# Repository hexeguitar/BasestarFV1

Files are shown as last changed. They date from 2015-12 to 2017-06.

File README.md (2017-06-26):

Basestar FV-1
========

### Spin Semiconductor FV-1 DSP development board

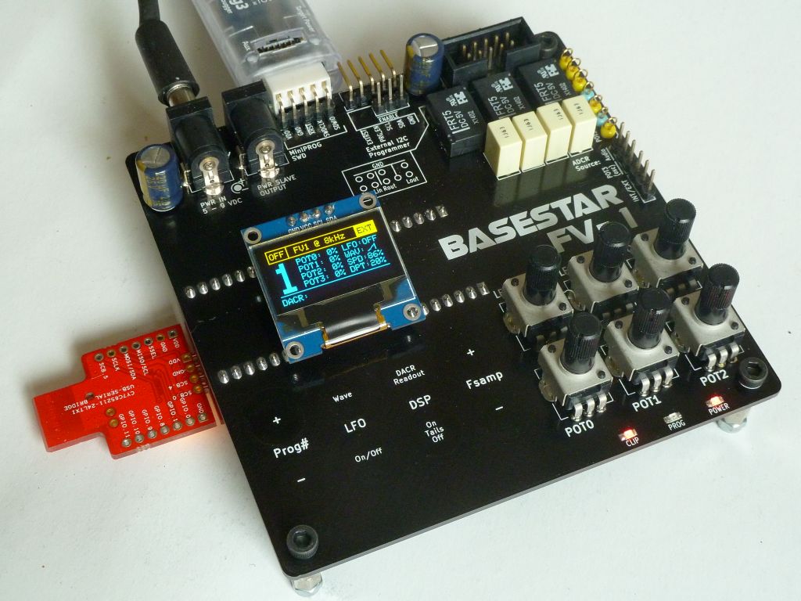
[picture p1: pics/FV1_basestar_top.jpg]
Basestar FV-1


Board is a part of modular DSP dev system including Dev_LOOP (analog IO) and a dedicated FV1 EEPROM Programmer

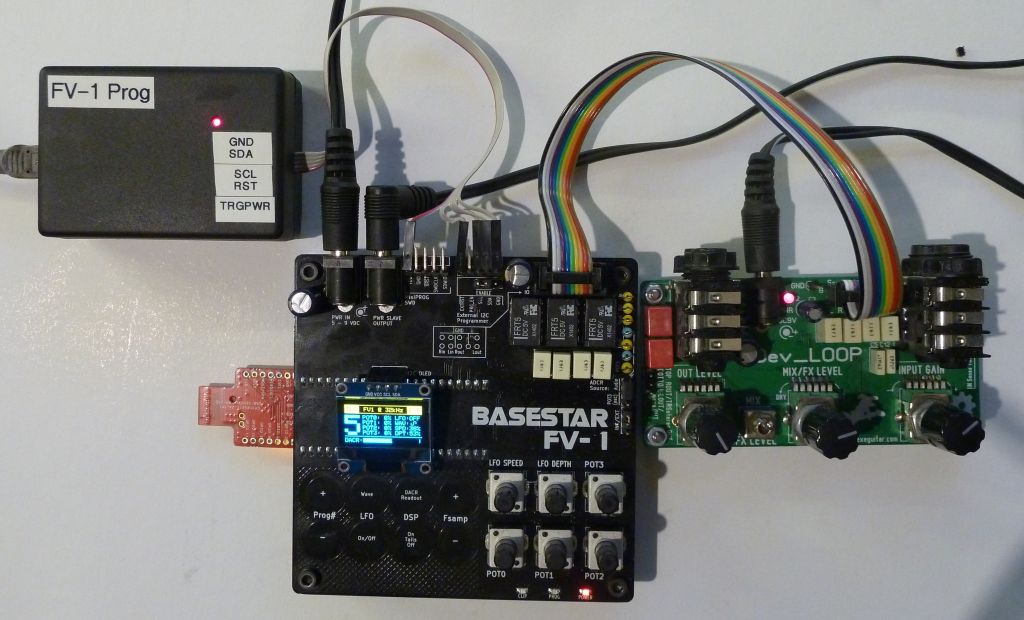
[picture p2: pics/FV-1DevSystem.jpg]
FV-1 Dev System


* [Dev_LOOP](http://www.hexeguitar.com/diy/utility/devloop)
* [FV-1 EEPROM Programmer](http://www.diystompboxes.com/smfforum/index.php?topic=112333.0)

### Project Site: http://www.hexeguitar.com/diy/utility/basefv1

License:  design is released under 

Creative Commons NonCommercial-ShareAlike 

CC BY-NC-SA



Please contact me for commercial opportunities.

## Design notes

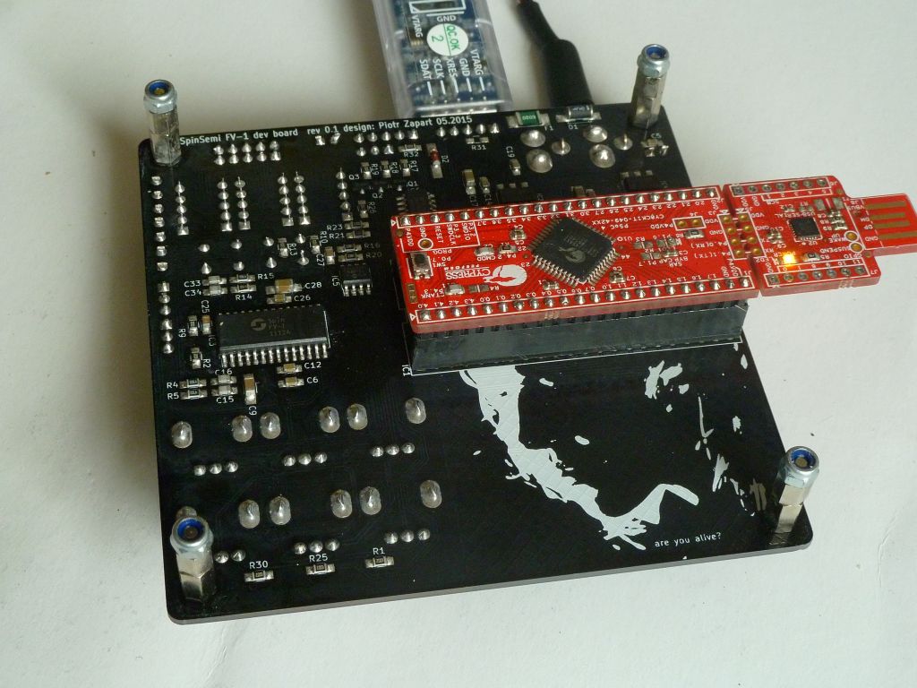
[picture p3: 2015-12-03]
pics/FV1_basestar_btm.jpg

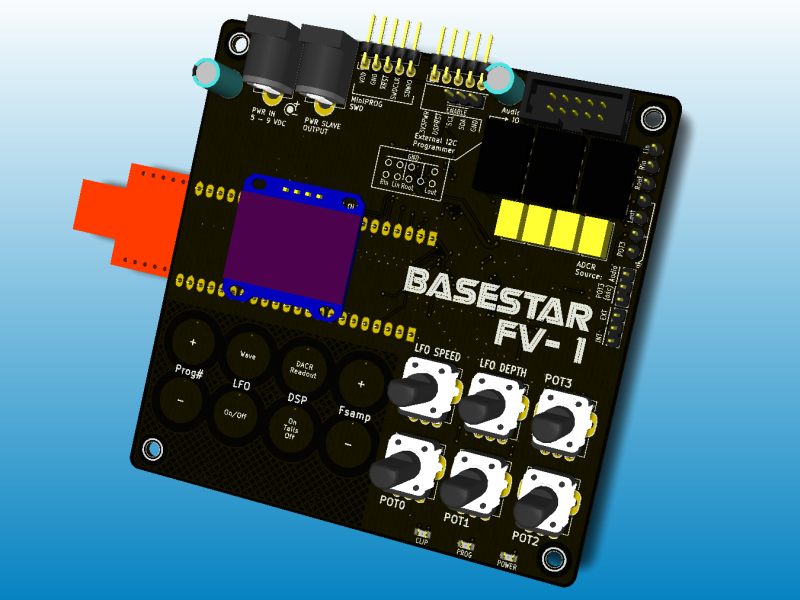
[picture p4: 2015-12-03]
pics/BasestarFV1_PCB_top.jpg

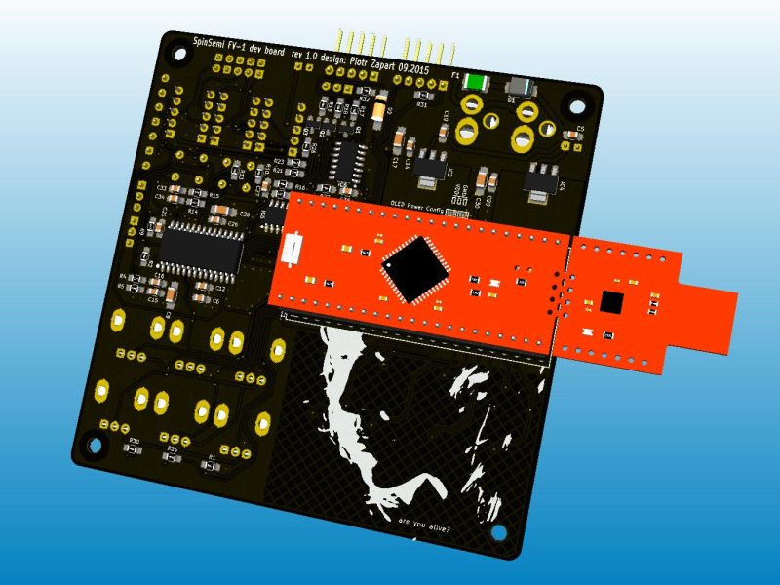
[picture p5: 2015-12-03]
pics/BasestarFV1_PCB_btm.jpg

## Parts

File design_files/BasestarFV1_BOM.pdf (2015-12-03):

## BASESTAR FV1 dev board BOM

© 2015 www.hexeguitar.com

Id | Designator | Package | Quantity | Desig./Value
1 | C15,C16,C33,C34 | C SMT 0805 | 4 | 1n/50V C0G
2 | C17,C30 | C SMT 1206 | 2 | 10µF/25V
3 | C21,C20,C8,C7 | C MKT RM5 | 4 | 1µF/63V
4 | C25 | C SMT 0805 | 1 | 1µF/25V
5 | C28,C9 | C SMT 1206 | 2 | 10µF/25V
6 | C3,C35 | El. Cap RM2.5/6.3mm | 2 | 220µF/25V
7 | C36,C1,C2,C4,C5,C6,C10,C11,C12,C13,C14,C18,C19, C22,C23,C24,C26,C27,C29,C31,C32 | C SMT 0805 | 21 | 100n
8 | CON1 | PWR Jack 5.5/2.1mm print | 1 | POWER_SLAVE
9 | CON2 | PWR Jack 5.5/2.1mm print | 1 | POWER_IN
10 | D1 | DO-214 | 1 | 1N4007
11 | D2 | MiniMELF | 1 | 1N4148
12 | D3,D6,D8 | LED-0805 | 3 | LED Red 0805
13 | F1 | Polyfuse 1812 | 1 | 200mA
14 | IC1 | CY8CKIT-049 | 1 | CY8CKIT-049
15 | IC2,IC4 | SOT-223 | 2 | LM1117-33
16 | IC3 | SOIC28_300MIL | 1 | FV-1
17 | IC5 | SOIC8 | 1 | 24LC32
18 | IC6 | SOIC14 | 1 | 74HC4066
19 | P1 | Header pin 1x3 RM2.54 | 1 | ADCR_SRC
20 | P10 | Header pin 1x4 RM2.54 | 1 | SSD1306 OLED
21 | P11 | Header pin 1x1 RM2.54 | 1 | ACCV
22 | P13 | Header pin 1x5 RM2.54 Angled | 1 | EEPROM Prog
23 | P14 | Header pin 1x5 RM2.54 Angled | 1 | MiniProg/KitProg
24 | P15 | IDC Socket 2x5 | 1 | AUDIO_IO
25 | P2 | Test point | 1 | ADCR
26 | P3 | Test point | 1 | ADCL
27 | P4 | Header pin 1x3 RM2.54 | 1 | PROG_ENABLE
28 | P5 | Header pin 1x3 RM2.54 | 1 | INT/EXT
29 | P6,P7 | Test point | 2 | GND
30 | P8 | Test point | 1 | DACL
31 | P9 | Test point | 1 | DACR
32 | Q1,Q2,Q3 | SOT-23 | 3 | BC847C
33 | R10,R13 | R SMT 0805 | 2 | 100k
34 | R11 | R SMT 0805 | 1 | 1k
35 | R17,R1,R2,R7,R8,R12,R18,R19,R25,R27,R30,R31,R32 | R SMT 0805 | 13 | 10k
36 | R21,R23,R26 | R SMT 0805 | 3 | 220R
37 | R29 | R SMT 0805 | 1 | 33R
38 | R3,R6,R16,R20 | R SMT 0805 | 4 | 2k2
39 | R4,R5,R14,R15,R22 | R SMT 0805 | 5 | 470R
40 | R9 | R SMT 0805 | 1 | 100R
41 | RLY2,RLY1,RLY3 | Relay DPDT DIP10 | 3 | FRT5-5V
42 | RV2,RV1,RV3,RV4,RV5,RV6 | ALPHA_RV09ACF-40 | 6 | 10k Lin

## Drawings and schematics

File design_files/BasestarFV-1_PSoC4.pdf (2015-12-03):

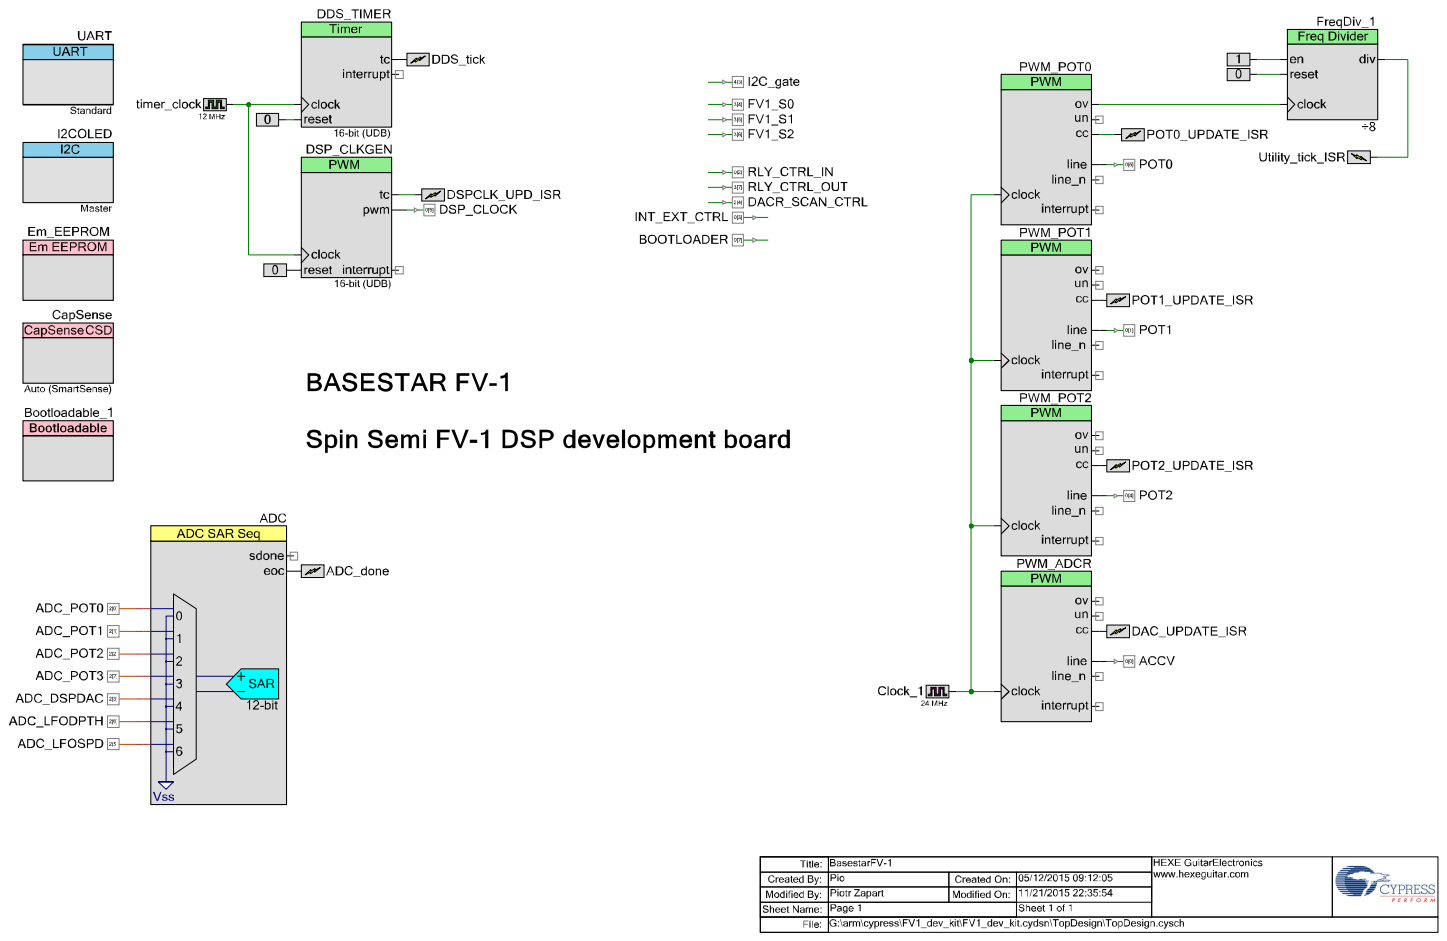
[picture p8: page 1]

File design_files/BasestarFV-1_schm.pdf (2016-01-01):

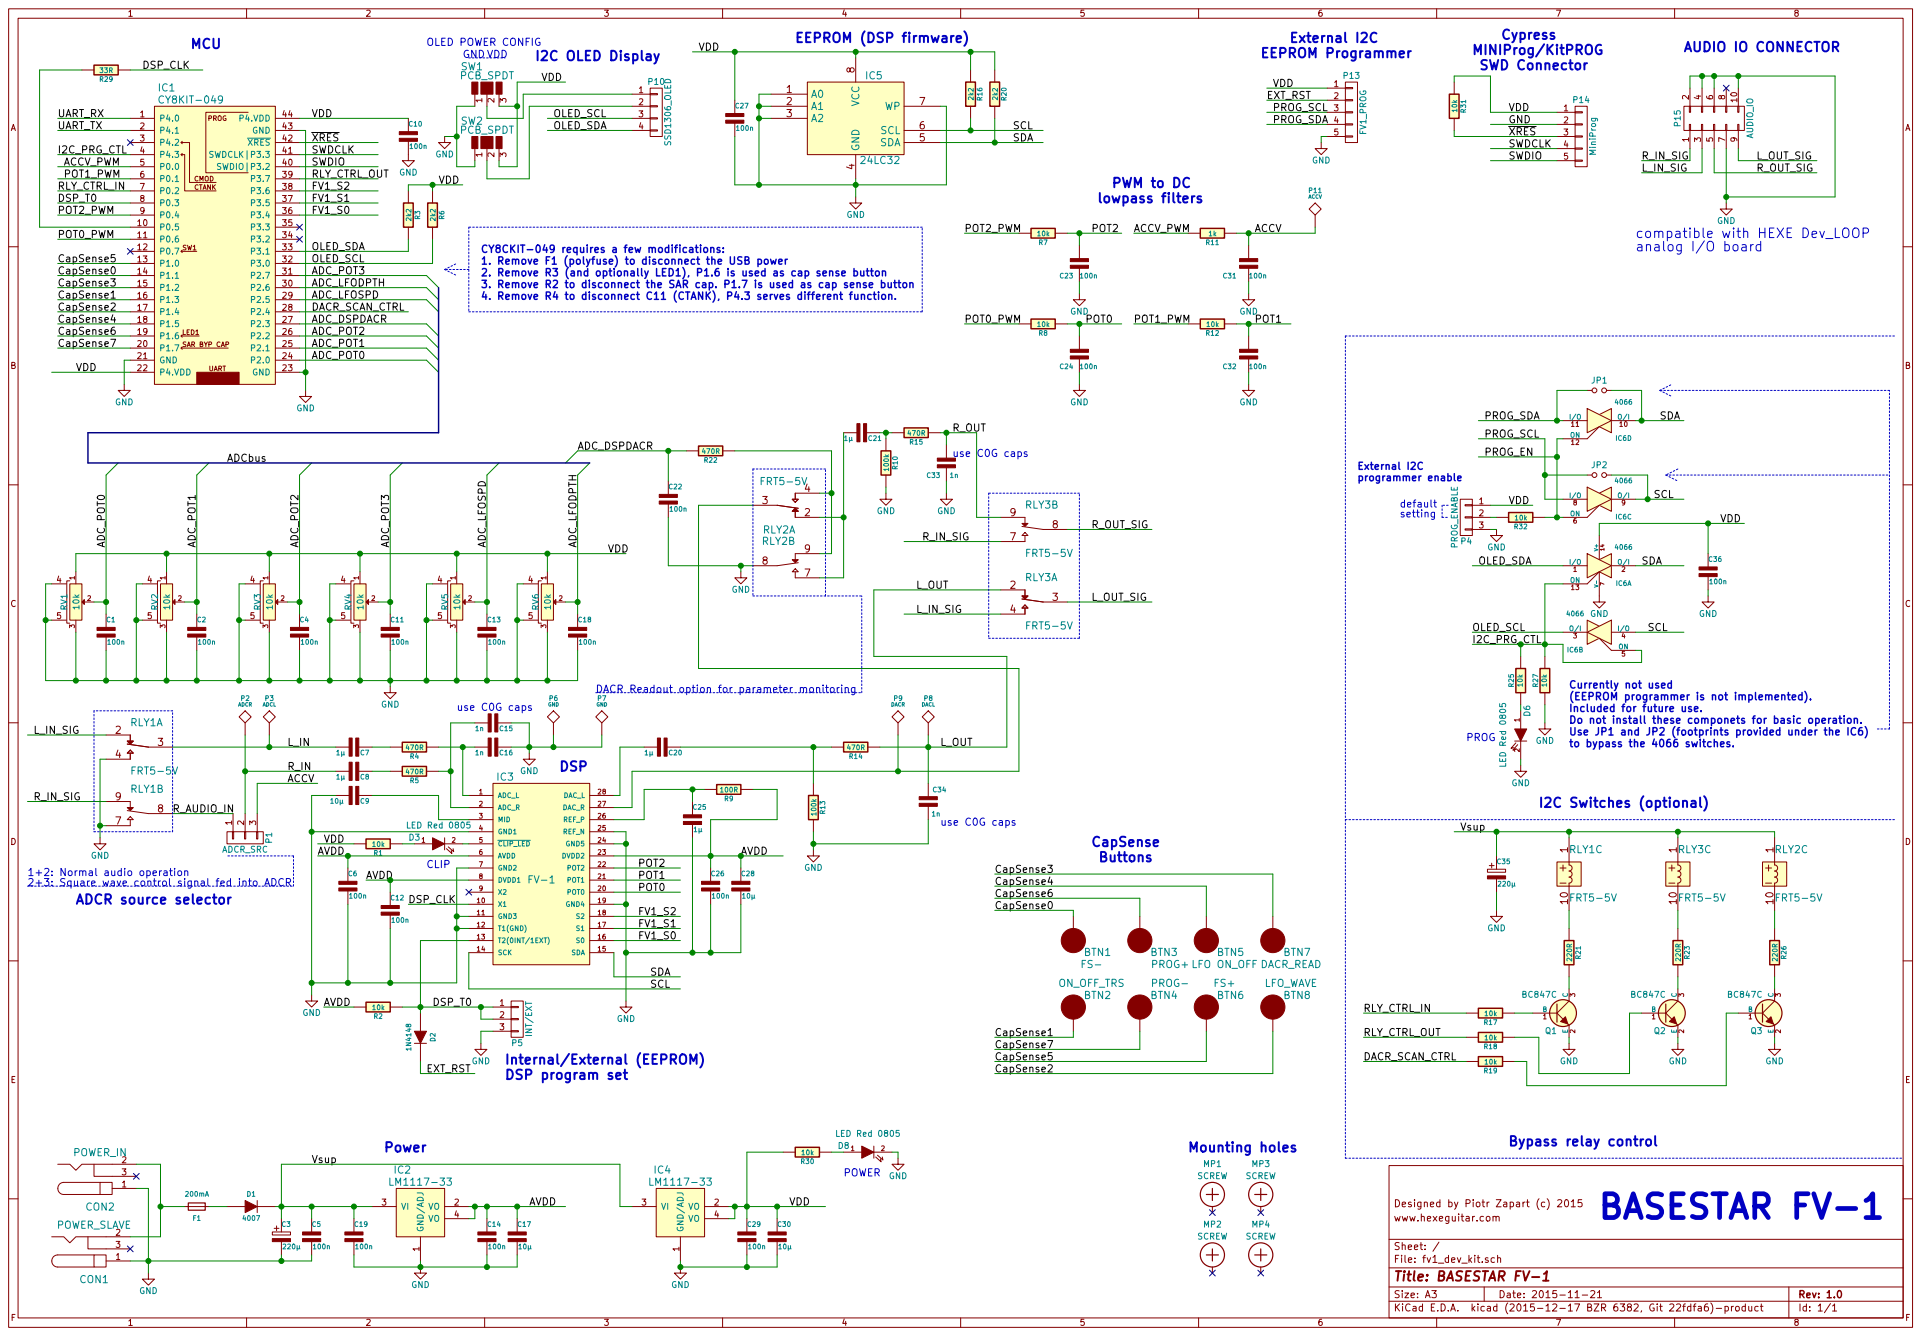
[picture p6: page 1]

EEPROM Programmer I2C OLED Display

CY8CKIT-049 requires a few modifications:
1. Remove F1 (polyfuse) to disconnect the USB power
2. Remove R3 (and optionally LED1), P1.6 is used as cap sense button
3. Remove R2 to disconnect the SAR cap. P1.7 is used as cap sense button
4. Remove R4 to disconnect C11 (CTANK), P4.3 serves different function.

ADC_LFODPTH
ADC_LFOSPD
DACR_SCAN_CTRL

ADC_POT2
ADC_POT1
ADC_POT0

to bypass the 4066 switches. default setting

Currently not used
(EEPROM programmer is not implemented).
Included for future use.
Do not install these componets for basic operation.
Use JP1 and JP2 (footprints provided under the IC6)

1+2: Normal audio operation
2+3: Square wave control signal fed into ADCR

POT1

DSP_CLK | | POT0

Bypass relay control Power

Designed by Piotr Zapart (c) 2015
File: fv1_dev_kit.sch Sheet: / www.hexeguitar.com

Id: 1/1 Title: BASESTAR FV-1

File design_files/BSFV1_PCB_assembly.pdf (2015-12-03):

# BASESTAR FV-1

# Spin Semiconductor FV-1 DSP development board

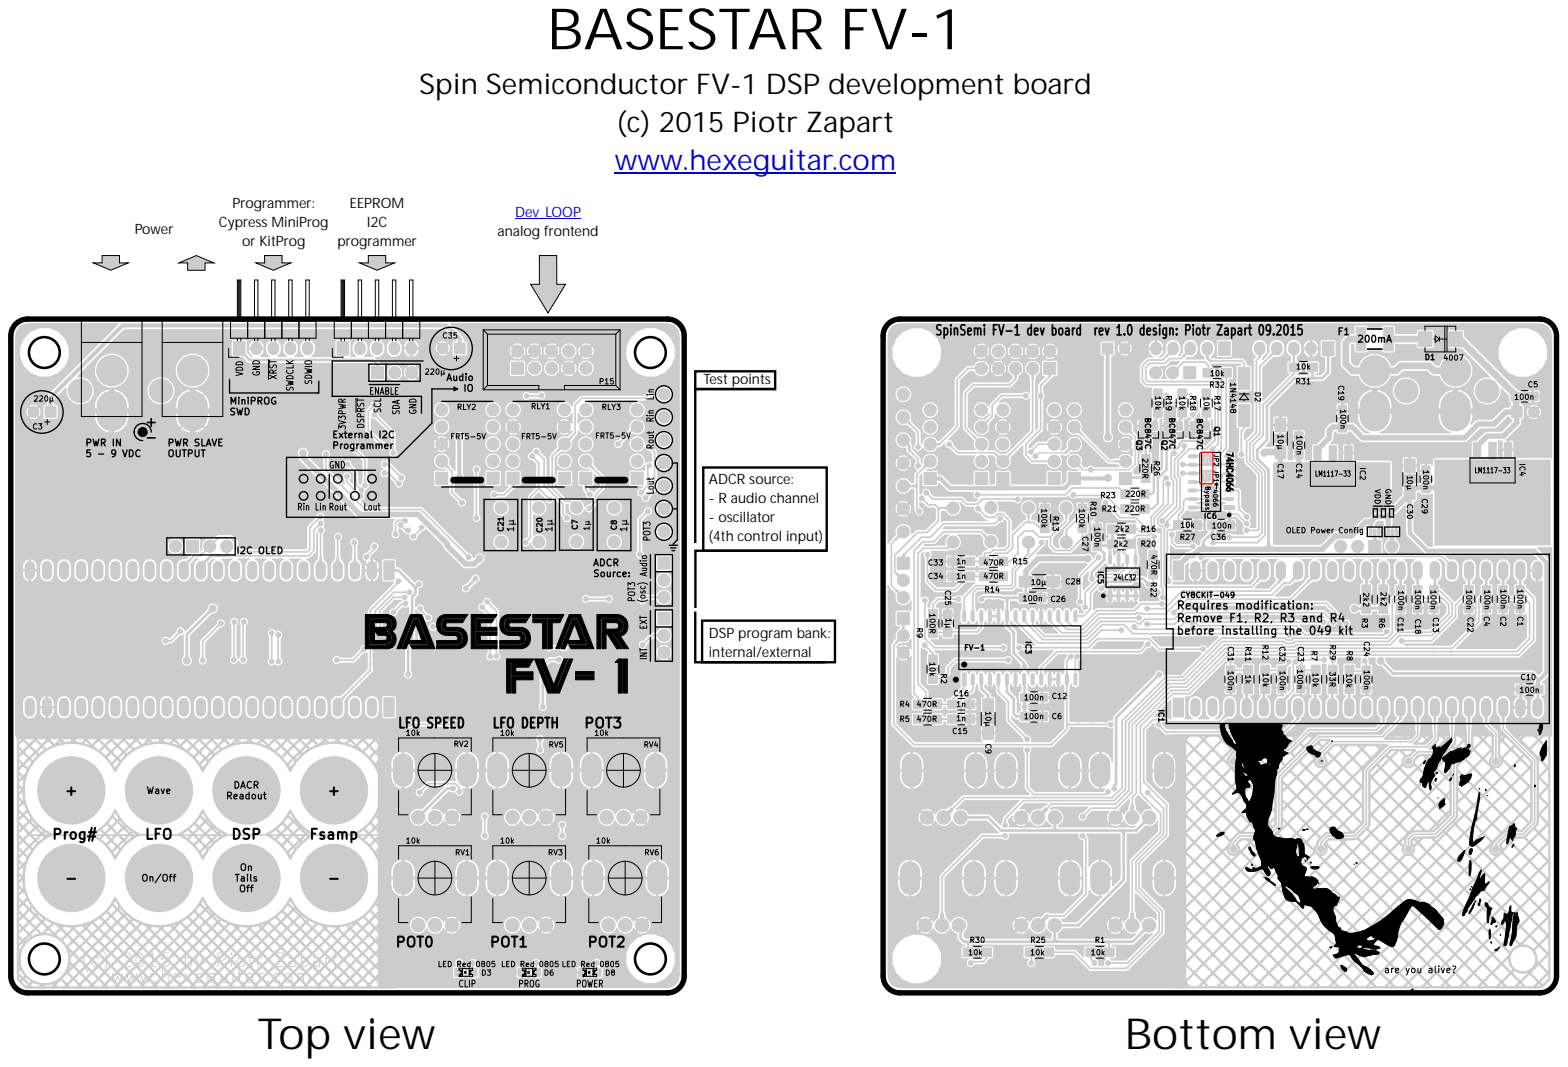
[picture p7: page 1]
EXT INT; Rin LinRout; Lout; GND; POT3; (osc)Audio; ADCR Source:; LFO SPEED; LFO DEPTH POT3; POT0; POT1; POT2; CLIP; PROG; POWER; Audio IO; External I2C Programmer; SDA; SCL; DSPRST; 3V3PWR; ENABLE; SDWIO; SWDCLK; XRST; VDD; MiniPROG SWD; PWR SLAVE OUTPUT; PWR IN 5 - 9 VDC; I2C OLED; DACR Readout; On Tails Off; DSP; Wave; On/Off; LFO; Prog#; Fsamp; RLY2; RLY1; RLY3; Top view; Bottom view; Programmer: Cypress MiniProg or KitProg; EEPROM I2C programmer; Dev_LOOP; Power; analog frontend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

(c) 2015 Piotr Zapart
www.hexeguitar.com

Lin Rin Rout Lout

DSP program bank:
internal/external
